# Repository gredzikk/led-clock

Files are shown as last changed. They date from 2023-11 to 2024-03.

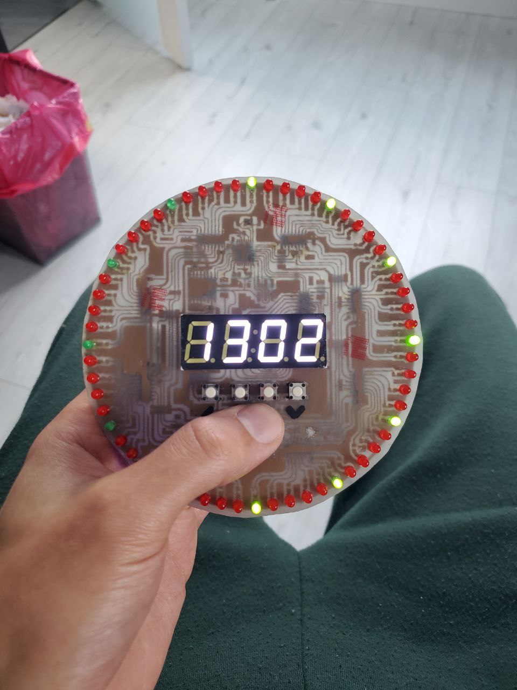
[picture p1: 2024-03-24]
photo_2024-03-24_16-38-59.jpg

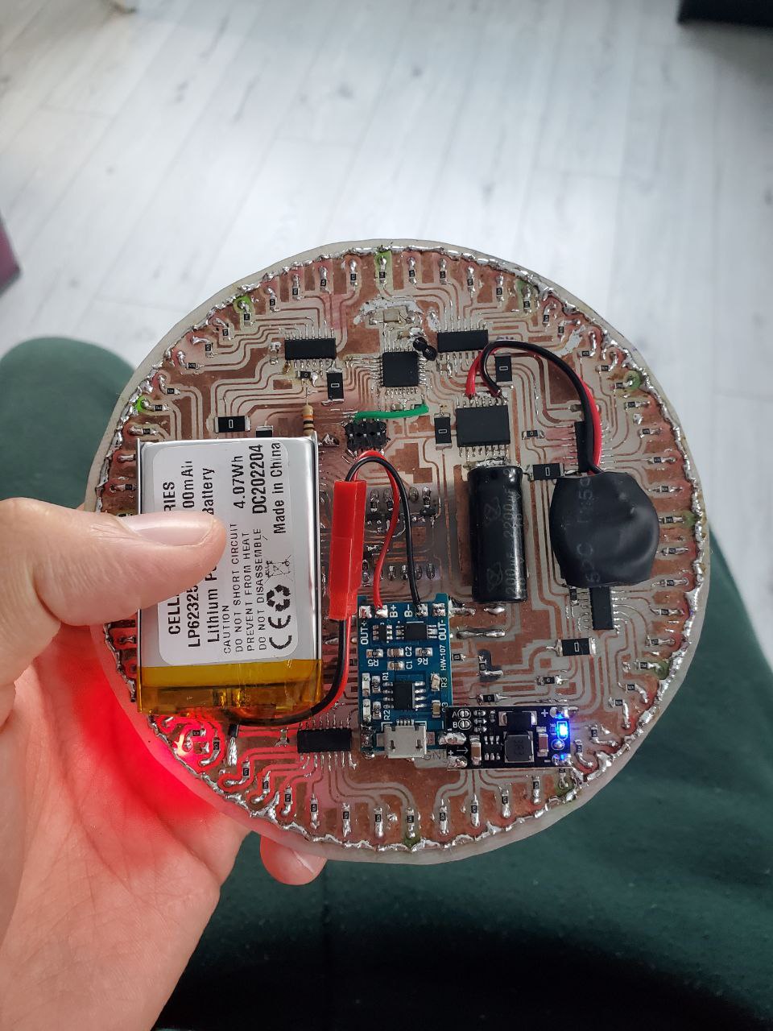
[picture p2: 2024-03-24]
photo_2024-03-24_16-39-03.jpg

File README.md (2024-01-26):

A project for Computer Science studies.
Clock consist of round PCB, ATmega328p with MiniCore bootloader driven by 12MHz crystal.
Clock IC is DS3231, time is displayed using 60 LEDs and 4 digit 7 segment display in the middle.
LEDs show seconds, 4digit can display hours, minutes, date, month and year.
Under the display 4 pushbuttons are used to change displayed values and program time.
DS3231 has CR2032 lithium battery power backup for keeping time without clock main power.
LEDs are driven by 8 HC595 shift registers, 4 digit display uses 2 HC595s.
Power is supplied by Liion battery through small 3.7-5V booster alongside with TP4056 charger.

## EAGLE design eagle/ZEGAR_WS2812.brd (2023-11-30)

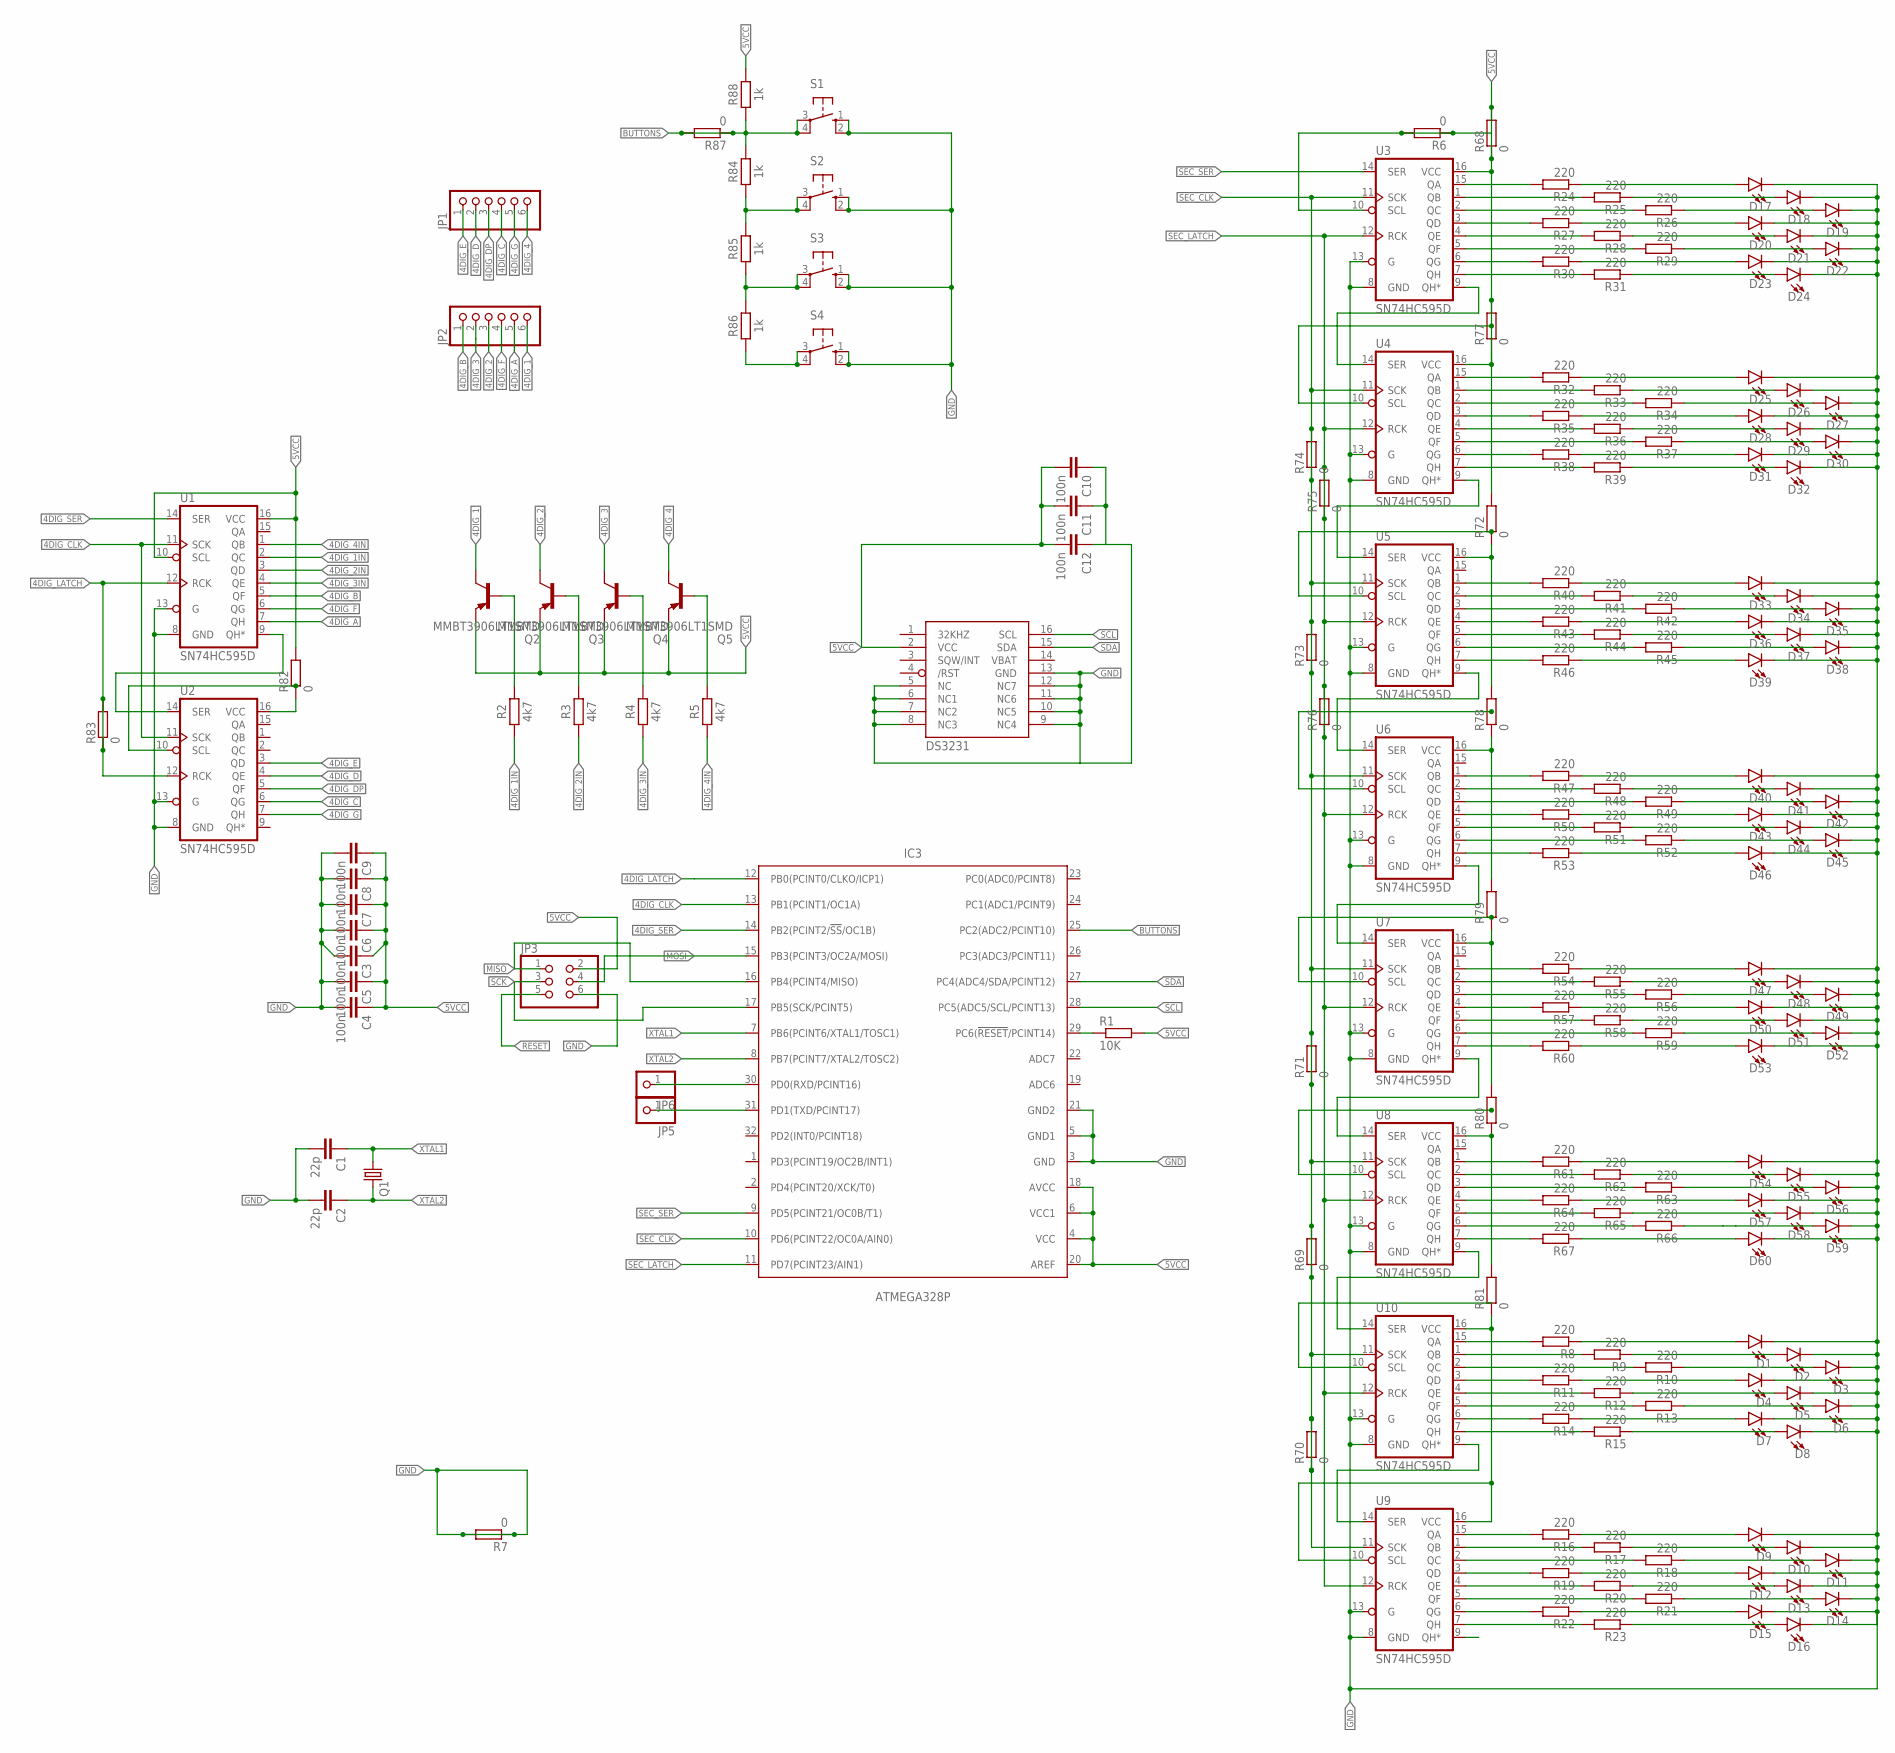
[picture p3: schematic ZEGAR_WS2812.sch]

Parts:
C1, C2: 22p; C0805
C3, C4, C5, C6, C7, C8, C9, C10, C11, C12: 100n; C0805
D1, D2, D3, D4, D5, D6, D7, D8, D9, D10, D11, D12, D13, D14, D15, D16, D17, D18, D19, D20, D21, D22, D23, D24, D25, D26, D27, D28, D29, D30, D31, D32, D33, D34, D35, D36, D37, D38, D39, D40, D41, D42, D43, D44, D45, D46, D47, D48, D49, D50, D51, D52, D53, D54, D55, D56, D57, D58, D59, D60: LED3MM; LED_3MM
IC2: DS3231/SO; SO16W
IC3: ATMEGA328P; TQFP32-08
JP1, JP2: PINHD-1X6; 1X06
JP3: PINHD-2X03_2.54-SMD; 2X03SMD
JP5, JP6: PINHD-1X01_2.54-SMD-90°; 1X01SMD/90
Q1: KX-7; 3.2X2.5_KX-7
Q2, Q3, Q4, Q5: MMBT3906LT1SMD; SOT23-BEC
R1: 10K; R0805
R2, R3, R4, R5: 4k7; RESC2012X65
R6, R68, R72, R77, R78, R79, R80, R81, R82, R83, R87: 0; R2512
R7, R69, R70, R71, R73, R74, R75, R76: 0; R1206
R8, R9, R10, R11, R12, R13, R14, R15, R16, R17, R18, R19, R20, R21, R22, R23, R24, R25, R26, R27, R28, R29, R30, R31, R32, R33, R34, R35, R36, R37, R38, R39, R40, R41, R42, R43, R44, R45, R46, R47, R48, R49, R50, R51, R52, R53, R54, R55, R56, R57, R58, R59, R60, R61, R62, R63, R64, R65, R66, R67: 220; R0805
R84, R85, R86, R88: 1k; RESC2012X65
S1, S2, S3, S4: 10-XX; B3F-10XX
U1, U2, U3, U4, U5, U6, U7, U8, U9, U10: SN74HC595D; SO16

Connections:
4DIG_1: JP2.6, Q2.C
4DIG_1IN: R2.1, U1.2 (QC)
4DIG_2: JP2.3, Q3.C
4DIG_2IN: R3.1, U1.3 (QD)
4DIG_3: JP2.2, Q4.C
4DIG_3IN: R4.1, U1.4 (QE)
4DIG_4: JP1.6, Q5.C
4DIG_4IN: R5.1, U1.1 (QB)
4DIG_A: JP2.5, U1.7 (QH)
4DIG_B: JP2.1, U1.5 (QF)
4DIG_C: JP1.4, U2.6 (QG)
4DIG_CLK: IC3.13 (PB1(PCINT1/OC1A)), U1.11 (SCK), U2.11 (SCK)
4DIG_D: JP1.2, U2.4 (QE)
4DIG_DP: JP1.3, U2.5 (QF)
4DIG_E: JP1.1, U2.3 (QD)
4DIG_F: JP2.4, U1.6 (QG)
4DIG_G: JP1.5, U2.7 (QH)
4DIG_LATCH: IC3.12 (PB0(PCINT0/CLKO/ICP1)), R83.1, R83.2, U1.12 (RCK), U2.12 (RCK)
4DIG_SER: IC3.14 (PB2(PCINT2/!SS!/OC1B)), U1.14 (SER)
5VCC: C3.1, C4.1, C5.1, C6.1, C7.1, C8.1, C9.1, C10.2, C11.2, C12.2, IC2.2 (VCC), IC3.4 (VCC), IC3.6 (VCC1), IC3.18 (AVCC), IC3.20 (AREF), JP3.2, Q2.E, Q3.E, Q4.E, Q5.E, R1.2, R6.1, R6.2, R68.1, R68.2, R72.1, R72.2, R77.1, R77.2, R78.1, R78.2, R79.1, R79.2, R80.1, R80.2, R81.1, R81.2, R82.1, R82.2, R88.2, U1.10 (SCL), U1.16 (VCC), U2.10 (SCL), U2.16 (VCC), U3.10 (SCL), U3.16 (VCC), U4.10 (SCL), U4.16 (VCC), U5.10 (SCL), U5.16 (VCC), U6.10 (SCL), U6.16 (VCC), U7.10 (SCL), U7.16 (VCC), U8.10 (SCL), U8.16 (VCC), U9.10 (SCL), U9.16 (VCC), U10.10 (SCL), U10.16 (VCC)
BUTTONS: IC3.25 (PC2(ADC2/PCINT10)), R84.2, R87.1, R87.2, R88.1, S1.3, S1.4 (P1)
GND: C1.2, C2.2, C3.2, C4.2, C5.2, C6.2, C7.2, C8.2, C9.2, C10.1, C11.1, C12.1, D1.K (C), D2.K (C), D3.K (C), D4.K (C), D5.K (C), D6.K (C), D7.K (C), D8.K (C), D9.K (C), D10.K (C), D11.K (C), D12.K (C), D13.K (C), D14.K (C), D15.K (C), D16.K (C), D17.K (C), D18.K (C), D19.K (C), D20.K (C), D21.K (C), D22.K (C), D23.K (C), D24.K (C), D25.K (C), D26.K (C), D27.K (C), D28.K (C), D29.K (C), D30.K (C), D31.K (C), D32.K (C), D33.K (C), D34.K (C), D35.K (C), D36.K (C), D37.K (C), D38.K (C), D39.K (C), D40.K (C), D41.K (C), D42.K (C), D43.K (C), D44.K (C), D45.K (C), D46.K (C), D47.K (C), D48.K (C), D49.K (C), D50.K (C), D51.K (C), D52.K (C), D53.K (C), D54.K (C), D55.K (C), D56.K (C), D57.K (C), D58.K (C), D59.K (C), D60.K (C), IC2.5 (NC), IC2.6 (NC1), IC2.7 (NC2), IC2.8 (NC3), IC2.9 (NC4), IC2.10 (NC5), IC2.11 (NC6), IC2.12 (NC7), IC2.13 (GND), IC3.3 (GND), IC3.5 (GND1), IC3.21 (GND2), JP3.6, R7.1, R7.2, S1.1 (S), S1.2 (S1), S2.1 (S), S2.2 (S1), S3.1 (S), S3.2 (S1), S4.1 (S), S4.2 (S1), U1.8 (GND), U1.13 (G), U2.8 (GND), U2.13 (G), U3.8 (GND), U3.13 (G), U4.8 (GND), U4.13 (G), U5.8 (GND), U5.13 (G), U6.8 (GND), U6.13 (G), U7.8 (GND), U7.13 (G), U8.8 (GND), U8.13 (G), U9.8 (GND), U9.13 (G), U10.8 (GND), U10.13 (G)
MISO: IC3.16 (PB4(PCINT4/MISO)), JP3.1
MOSI: IC3.15 (PB3(PCINT3/OC2A/MOSI)), JP3.4
unnamed: U1.9 (QH*), U2.14 (SER)
unnamed: U9.14 (SER), U10.9 (QH*)
unnamed: R8.2, U10.15 (QA)
unnamed: R9.2, U10.1 (QB)
unnamed: R10.2, U10.2 (QC)
unnamed: R11.2, U10.3 (QD)
unnamed: R12.2, U10.4 (QE)
unnamed: R13.2, U10.5 (QF)
unnamed: U7.9 (QH*), U8.14 (SER)
unnamed: U6.9 (QH*), U7.14 (SER)
unnamed: U5.9 (QH*), U6.14 (SER)
unnamed: U4.9 (QH*), U5.14 (SER)
unnamed: U3.9 (QH*), U4.14 (SER)
unnamed: R14.2, U10.6 (QG)
unnamed: R15.2, U10.7 (QH)
unnamed: R16.2, U9.15 (QA)
unnamed: Q2.B, R2.2
unnamed: Q3.B, R3.2
unnamed: Q4.B, R4.2
unnamed: Q5.B, R5.2
unnamed: R17.2, U9.1 (QB)
unnamed: R18.2, U9.2 (QC)
unnamed: R19.2, U9.3 (QD)
unnamed: R20.2, U9.4 (QE)
unnamed: R21.2, U9.5 (QF)
unnamed: R22.2, U9.6 (QG)
unnamed: R23.2, U9.7 (QH)
unnamed: R24.2, U3.15 (QA)
unnamed: R25.2, U3.1 (QB)
unnamed: R26.2, U3.2 (QC)
unnamed: R27.2, U3.3 (QD)
unnamed: R28.2, U3.4 (QE)
unnamed: R29.2, U3.5 (QF)
unnamed: R30.2, U3.6 (QG)
unnamed: R31.2, U3.7 (QH)
unnamed: R32.2, U4.15 (QA)
unnamed: R33.2, U4.1 (QB)
unnamed: R34.2, U4.2 (QC)
unnamed: R35.2, U4.3 (QD)
unnamed: R36.2, U4.4 (QE)
unnamed: R37.2, U4.5 (QF)
unnamed: R38.2, U4.6 (QG)
unnamed: R39.2, U4.7 (QH)
unnamed: R47.2, U6.1 (QB)
unnamed: R40.2, U5.1 (QB)
unnamed: R41.2, U5.2 (QC)
unnamed: R42.2, U5.3 (QD)
unnamed: R43.2, U5.4 (QE)
unnamed: R44.2, U5.5 (QF)
unnamed: R45.2, U5.6 (QG)
unnamed: R46.2, U5.7 (QH)
unnamed: R48.2, U6.2 (QC)
unnamed: R49.2, U6.3 (QD)
unnamed: R50.2, U6.4 (QE)
unnamed: R51.2, U6.5 (QF)
unnamed: R52.2, U6.6 (QG)
unnamed: R53.2, U6.7 (QH)
unnamed: R54.2, U7.1 (QB)
unnamed: R55.2, U7.2 (QC)
unnamed: R56.2, U7.3 (QD)
unnamed: R57.2, U7.4 (QE)
unnamed: R58.2, U7.5 (QF)
unnamed: R59.2, U7.6 (QG)
unnamed: R60.2, U7.7 (QH)
unnamed: R61.2, U8.1 (QB)
unnamed: R62.2, U8.2 (QC)
unnamed: R63.2, U8.3 (QD)
unnamed: R64.2, U8.4 (QE)
unnamed: R65.2, U8.5 (QF)
unnamed: R66.2, U8.6 (QG)
unnamed: R67.2, U8.7 (QH)
unnamed: D1.A, R8.1
unnamed: D2.A, R9.1
unnamed: D4.A, R11.1
unnamed: D3.A, R10.1
unnamed: D7.A, R14.1
unnamed: D5.A, R12.1
unnamed: D6.A, R13.1
unnamed: D8.A, R15.1
unnamed: D9.A, R16.1
unnamed: D12.A, R19.1
unnamed: D15.A, R22.1
unnamed: D17.A, R24.1
unnamed: D18.A, R25.1
unnamed: D19.A, R26.1
unnamed: D10.A, R17.1
unnamed: D13.A, R20.1
unnamed: D11.A, R18.1
unnamed: D16.A, R23.1
unnamed: D14.A, R21.1
unnamed: D23.A, R30.1
unnamed: D22.A, R29.1
unnamed: D21.A, R28.1
unnamed: D20.A, R27.1
unnamed: D24.A, R31.1
unnamed: D25.A, R32.1
unnamed: D26.A, R33.1
unnamed: D27.A, R34.1
unnamed: D28.A, R35.1
unnamed: D29.A, R36.1
unnamed: D30.A, R37.1
unnamed: D31.A, R38.1
unnamed: D32.A, R39.1
unnamed: D33.A, R40.1
unnamed: D34.A, R41.1
unnamed: D35.A, R42.1
unnamed: D36.A, R43.1
unnamed: D37.A, R44.1
unnamed: D38.A, R45.1
unnamed: D39.A, R46.1
unnamed: D40.A, R47.1
unnamed: D41.A, R48.1
unnamed: D42.A, R49.1
unnamed: D43.A, R50.1
unnamed: D44.A, R51.1
unnamed: D45.A, R52.1
unnamed: D46.A, R53.1
unnamed: D47.A, R54.1
unnamed: D48.A, R55.1
unnamed: D49.A, R56.1
unnamed: D50.A, R57.1
unnamed: D51.A, R58.1
unnamed: D52.A, R59.1
unnamed: D53.A, R60.1
unnamed: D54.A, R61.1
unnamed: D55.A, R62.1
unnamed: D56.A, R63.1
unnamed: D57.A, R64.1
unnamed: D60.A, R67.1
unnamed: D59.A, R66.1
unnamed: D58.A, R65.1
unnamed: IC3.30 (PD0(RXD/PCINT16)), JP6.1
unnamed: IC3.31 (PD1(TXD/PCINT17)), JP5.1
unnamed: R84.1, R85.2, S2.3, S2.4 (P1)
unnamed: R85.1, R86.2, S3.3, S3.4 (P1)
unnamed: R86.1, S4.3, S4.4 (P1)
RESET: IC3.29 (PC6(!RESET!/PCINT14)), JP3.5, R1.1
SCK: IC3.17 (PB5(SCK/PCINT5)), JP3.3
SCL: IC2.16 (SCL), IC3.28 (PC5(ADC5/SCL/PCINT13))
SDA: IC2.15 (SDA), IC3.27 (PC4(ADC4/SDA/PCINT12))
SEC_CLK: IC3.10 (PD6(PCINT22/OC0A/AIN0)), R69.1, R69.2, R70.1, R70.2, R71.1, R71.2, R73.1, R73.2, R74.1, R74.2, U3.11 (SCK), U4.11 (SCK), U5.11 (SCK), U6.11 (SCK), U7.11 (SCK), U8.11 (SCK), U9.11 (SCK), U10.11 (SCK)
SEC_LATCH: IC3.11 (PD7(PCINT23/AIN1)), R75.1, R75.2, R76.1, R76.2, U3.12 (RCK), U4.12 (RCK), U5.12 (RCK), U6.12 (RCK), U7.12 (RCK), U8.12 (RCK), U9.12 (RCK), U10.12 (RCK)
SEC_SER: IC3.9 (PD5(PCINT21/OC0B/T1)), U3.14 (SER)
SEC_SERIAL: U8.9 (QH*), U10.14 (SER)
VBAT: IC2.14 (VBAT)
XTAL1: C1.1, IC3.7 (PB6(PCINT6/XTAL1/TOSC1)), Q1.1
XTAL2: C2.1, IC3.8 (PB7(PCINT7/XTAL2/TOSC2)), Q1.3 (2)

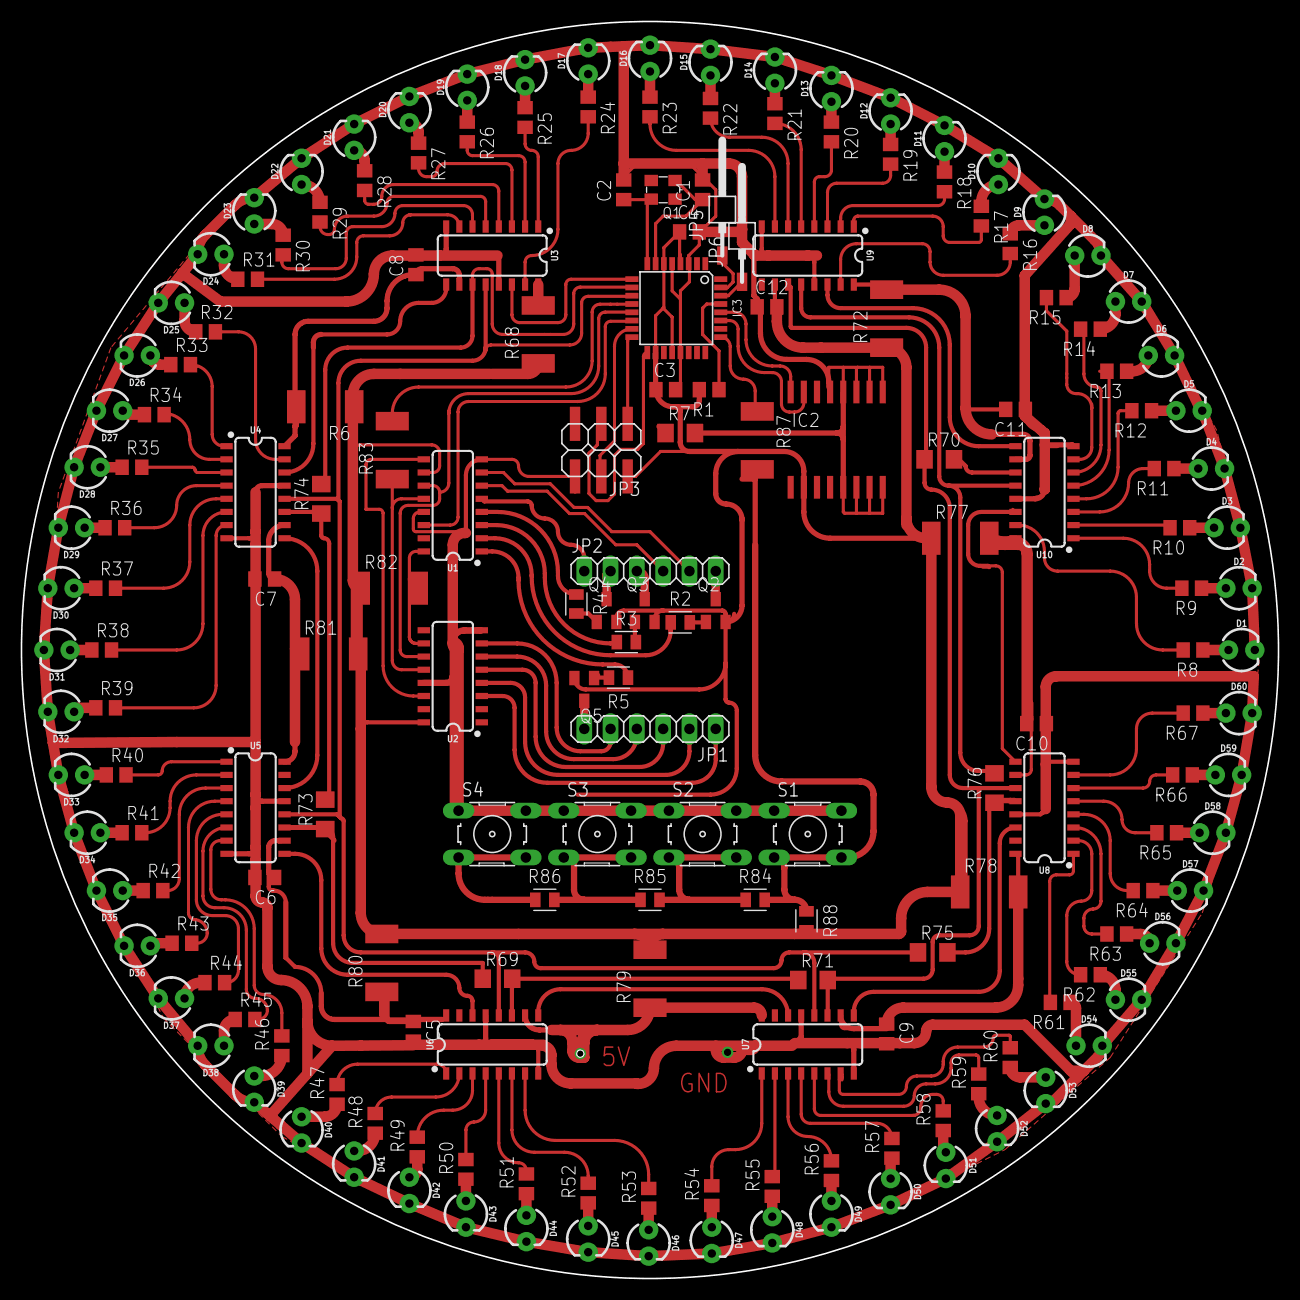
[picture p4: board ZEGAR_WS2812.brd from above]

Board: 2 copper layers, 121.4 x 121.4 mm, 186 parts (0 on the bottom side), 170 nets.

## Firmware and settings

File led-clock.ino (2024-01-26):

#include <bitBangedSPI.h>
#include <Wire.h>
#include <DS3231.h>
#include "SevSegShift.h"

#define SHIFT_PIN_DS   10
#define SHIFT_PIN_STCP 8
#define SHIFT_PIN_SHCP 9

#define BUTTON_PIN A2

SevSegShift sevseg(SHIFT_PIN_DS, SHIFT_PIN_SHCP, SHIFT_PIN_STCP); //Instantiate a seven segment controller object

DS3231 zegar;

bool h12Flag = false;
bool pmFlag = false;
bool monthFlag = false;

int adjustedSeconds[] = {64, 
                          1,  2,  3,  4,  5,  6,  7,  8,
                          9,  10, 11, 12, 13, 14, 15, 16,
                          18, 19, 20, 21, 22, 23, 24, 26,
                          27, 28, 29, 30, 31, 32, 34, 35,
                          36, 37, 38, 39, 40, 42, 43, 44,
                          45, 46, 47, 48, 49, 50, 51, 52,
                          53, 54, 55, 56, 57, 58, 59, 60,
                          61, 62, 63 };
                                
bitBangedSPI bbSPI(5, bitBangedSPI::NO_PIN, 6);

const uint8_t LATCH = 7;

const byte numberOfChips = 8;
const byte maxLEDs = numberOfChips * 8;

typedef struct LedInfo
{
  int chip;
  byte mask;
} LedInfo;

bool ready = false;
short readyMillis = 200;

bool timeIsLoaded;

int keyPressed;
int screenId = 0;
int prevScreen = 0;

int date;

int monthLength[] = {31, 28, 31, 30, 31, 30, 31, 31, 30, 31, 30, 31};

const int btnNONE = 0;
const int btnUP = 1;
const int btnDOWN = 2;
const int btnLEFT = 3;
const int btnRIGHT = 4;

unsigned long previousMillisButton = 0;

int readAnalogButton() {
  int val = analogRead(BUTTON_PIN);

  if (val < 100) return btnLEFT;
  if (val < 550) return btnRIGHT;
  if (val < 725) return btnUP;
  if (val < 850) return btnDOWN;

  return btnNONE;  // when all others fail, return this.
}

int timeToDisplay;

int yearToSet, monthToSet, DoWToSet, dayToSet, hourToSet, minuteToSet, secondToSet;

void lcdDisplayPage(unsigned int screenId) {
  switch (screenId) {
    case 0:
      {
        sevseg.setNumber(timeToDisplay);
        break;
      }
    case 1:
      {
        sevseg.setNumber(date);
        break;
      }
    case 2:
      {
        sevseg.setNumber(2024);
        break;
      }
    case 3:
      {
        sevseg.blank();
        break;
      }
    case 4:
      {
        if (!timeIsLoaded) {
          yearToSet = zegar.getYear();
          monthToSet = zegar.getMonth(monthFlag);
          dayToSet = zegar.getDate();
          DoWToSet = zegar.getDoW();
          hourToSet = zegar.getHour(h12Flag, pmFlag);
          minuteToSet = zegar.getMinute();
          secondToSet = zegar.getSecond();

          timeIsLoaded = true;
        }

        sevseg.setChars("SET");
        if (keyPressed == btnUP)
          saveParams();
        break;
      }
    case 5:
      {
        sevseg.setNumber(minuteToSet);
        break;
      }
    case 6:
      {
        sevseg.setNumber(hourToSet);
        break;
      }
    case 7:
      {
        sevseg.setNumber(dayToSet);
        break;
      }
    case 8:
      {
        sevseg.setNumber(monthToSet);
        break;
      }
    case 9:
      {
        sevseg.setNumber(yearToSet);
        break;
      }
  }
}

void saveParams() {
  zegar.setYear(yearToSet);
  zegar.setMonth(monthToSet);
  zegar.setDate(dayToSet);
  zegar.setDoW(DoWToSet);
  zegar.setHour(hourToSet);
  zegar.setMinute(minuteToSet);

  clearLED(0);
  setLED(adjustedSeconds[0]);
  setLED(adjustedSeconds[5]);
  setLED(adjustedSeconds[10]);
  setLED(adjustedSeconds[15]);
  setLED(adjustedSeconds[20]);
  setLED(adjustedSeconds[25]);
  setLED(adjustedSeconds[30]);
  setLED(adjustedSeconds[35]);
  setLED(adjustedSeconds[40]);
  setLED(adjustedSeconds[45]);
  setLED(adjustedSeconds[50]);
  setLED(adjustedSeconds[55]);
  refreshLEDs();
  delay(100);
  clearLED(0);

  timeIsLoaded = false;
  
}

byte LEDdata[numberOfChips] = {0}; // initial pattern

void refreshLEDs()
{
  //clearLED(0);
  digitalWrite(LATCH, LOW);
  for (int i = numberOfChips - 1; i >= 0; i--)
    bbSPI.transfer(LEDdata[i]);
  digitalWrite(LATCH, HIGH);
} // end of refreshLEDs

// turn an LED number into the position in the array, and a bit mask
boolean getChipAndBit(unsigned int led, LedInfo &ledInfo)
{
  led--;
  // divide by 8 to work out which chip
  ledInfo.chip = led / 8; // which chip
  // remainder is bit number
  ledInfo.mask = 1 << (led % 8);
} // end of getChipAndBit

// clear LED n (or all if zero)
void clearLED(const long n)
{
  // zero means all
  if (n == 0)
  {
    for (int i = 0; i < numberOfChips; i++)
      LEDdata[i] = 0;
    return;
  } // end of if zero
  
  LedInfo ledInfo;
  if (getChipAndBit(n, ledInfo))
    return; // bad number

  LEDdata[ledInfo.chip] &= ~ledInfo.mask;
} // end of clearLED

// set LED n (or all if zero)
void setLED(const long n)
{
  // zero means all
  if (n == 0)
  {
    for (int i = 0; i < numberOfChips; i++)
      LEDdata[i] = 0xFF;
    return;
  } // end of if zero

  LedInfo ledInfo;
  if (getChipAndBit(n, ledInfo))
    return; // bad number

  LEDdata[ledInfo.chip] |= ledInfo.mask;
} // end of setLED

void unready() {
  ready = false;
}

void nextPage() {
  ++screenId;
}

void prevPage() {
  --screenId;
}

void increment (int screenId) {
  switch (screenId) {
    case 5:
    {
      minuteToSet++;
      if (minuteToSet > 59)
        minuteToSet = 0;
      break;
    }
    case 6:
    {
      hourToSet++;
      if (hourToSet > 23)
        hourToSet = 0;
      break;
    }
    case 7:
    {
      dayToSet++;
      if (dayToSet > monthLength[monthToSet-1])
        dayToSet = 1;
      break;
    }
    case 8:
    {
      monthToSet++;
      if (monthToSet > 12)
        monthToSet = 1;
      break;
    }
    case 9:
    {
      yearToSet++;
      if (yearToSet > 2069)
        yearToSet = 2024;
      break;
    }
    deafult:
    {
      break;
    }
  }
}

void decrement (int screenId) {
  switch (screenId) {
    case 5:
    {
      minuteToSet--;
      if (minuteToSet < 0)
        minuteToSet = 59;
      break;
    }
    case 6:
    {
      hourToSet--;
      if (hourToSet < 0)
        hourToSet = 23;
      break;
    }
    case 7:
    {
      dayToSet--;
      if (dayToSet < 1)
        dayToSet = monthLength[monthToSet-1];
      break;
    }
    case 8:
    {
      monthToSet--;
      if (monthToSet < 1)
        monthToSet = 12;
      break;
    }
    case 9:
    {
      yearToSet--;
      if (yearToSet < 2024)
        yearToSet = 2069;
      break;
    }
    default:
    {
      break;
    }
  }
}

void setup()
{
  Serial.begin(9600);
  Serial.println("enter setup");
  bbSPI.begin();
  pinMode(LATCH, OUTPUT);

  Serial.println("Starting ...");
  Wire.begin();

  byte numDigits = 4;
  byte digitPins[] = {2, 3, 4, 1}; // of ShiftRegister(s) | 8+x (2nd Register)
  byte segmentPins[] = {7, 5, 8+6, 8+4, 8+3, 6, 8+7, 8+5}; // of Shiftregister(s) | 8+x (2nd Register)
  bool resistorsOnSegments = false; // 'false' means resistors are on digit pins
  byte hardwareConfig = P_TRANSISTORS; // See README.md for options
  bool updateWithDelays = false; // Default 'false' is Recommended
  bool leadingZeros = true; // Use 'true' if you'd like to keep the leading zeros
  bool disableDecPoint = false; // Use 'true' if your decimal point doesn't exist or isn't connected

  sevseg.begin(hardwareConfig, numDigits, digitPins, segmentPins, resistorsOnSegments,
  updateWithDelays, leadingZeros, disableDecPoint);
  sevseg.setBrightness(1);

  yearToSet = zegar.getYear();
  monthToSet = zegar.getMonth(monthFlag);
  dayToSet = zegar.getDate();
  DoWToSet = zegar.getDoW();
  hourToSet = zegar.getHour(h12Flag, pmFlag);
  minuteToSet = zegar.getMinute();
  secondToSet = zegar.getSecond();
} // end of setup

int second, prevSecond;
int minute, prevMinute;

void loop()
{
  unsigned long currentMillis = millis();

  keyPressed = readAnalogButton();
  screenId = constrain(screenId, 0, 9);

  if (!ready && keyPressed && currentMillis - previousMillisButton >= readyMillis) {
    ready = true;
    previousMillisButton = currentMillis;
  }

  second = zegar.getSecond();
  minute = zegar.getMinute();

  switch (keyPressed) {
    case btnRIGHT:
    {
      if (ready)
        nextPage();
      unready();
      break;
    }
    case btnLEFT:
    {
      if (ready)
        prevPage();
      unready();
      break;
    }
    case btnDOWN:
    {
      if (ready)
        decrement(screenId);
      unready();
      break;
    }
    case btnUP:
    {
      if (ready)
        increment(screenId);
      unready();
      break;
    }

  }
  
  lcdDisplayPage(screenId);
  if (screenId != prevScreen) {
    prevScreen = screenId;
  }

  if (second != prevSecond) {
    if (second == 0)
      clearLED(0);
    clearLED(adjustedSeconds[prevSecond]);
    for (int i = 0; i < second; ++i)
      if (i % 5 == 0)
        setLED(adjustedSeconds[i]);
    refreshLEDs();
    setLED(adjustedSeconds[second]);
    refreshLEDs();
    prevSecond = second;
  }

  if (minute != prevMinute)
  {
    timeToDisplay = zegar.getHour(h12Flag, pmFlag) * 100 + minute;
    date = zegar.getDate() * 100 + zegar.getMonth(monthFlag);
    sevseg.setNumber(timeToDisplay);
    prevMinute = minute;
  }  

  sevseg.refreshDisplay();
} 

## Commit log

2023-11-27 all elements in place
    [ZEGAR_WS2812.brd, ZEGAR_WS2812.sch]
2023-11-27 fixed hc595 posiiton
    [ZEGAR_WS2812.brd]
2023-11-28 placed traces from diodes to shift registers
    [ZEGAR_WS2812.brd, ZEGAR_WS2812.sch]
2023-11-28 hc595 for seconds completed
    [ZEGAR_WS2812.brd, ZEGAR_WS2812.sch]
2023-11-30 almost done
    [ZEGAR_WS2812.brd, ZEGAR_WS2812.sch]
2023-11-30 added programming pins and rx tx pins
    [ZEGAR_WS2812.brd, ZEGAR_WS2812.sch]
2023-11-30 adjusted some traces
    [ZEGAR_WS2812.brd]
2024-01-26 Update and rename sketch_dec8b.ino to led-clock.ino

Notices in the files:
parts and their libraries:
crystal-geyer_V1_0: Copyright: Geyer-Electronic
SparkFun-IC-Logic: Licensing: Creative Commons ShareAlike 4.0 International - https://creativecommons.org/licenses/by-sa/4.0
